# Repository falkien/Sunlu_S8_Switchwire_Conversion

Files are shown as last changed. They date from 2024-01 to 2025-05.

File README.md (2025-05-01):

# Sunlu_S8_Switchwire_Conversion

***UPDATE 05/01/25*** I recently sold my Switchwire. I am going to leave this page up for anyone in the future looking for info on a Sunlu S8 Switchwire conversion

***UPDATE 07/27/24*** Look for major changes in this entire section over the next couple of weeks. I am redoing the entire electronics and Skirt area. This includes all new skirts, upgrade to the SKR Mini E3 V3, and replacing the PVC electronic cover panels with printed pieces. 

You will find here all the files needed to upgrade your Sunlu S8 to a Voron Switchwire. This is a work in progress so please bear with me. <br />
<br />
This will hopefully have everything that you need to do a conversion. It has taken me several months to get this up and running and I will also be updating this as I go, so excuse the gramar and layout as I am new to github.  <br />
 <br />
Rails purchased <br />
<br />
(4) 450mm - (2) MGN12H rails for Y and (2) MGN12H rails for Z <br />
<br />
(1) 348mm - MGN12H rail for X <- Custom cut to fit, could use a 350mm <br />
<br />
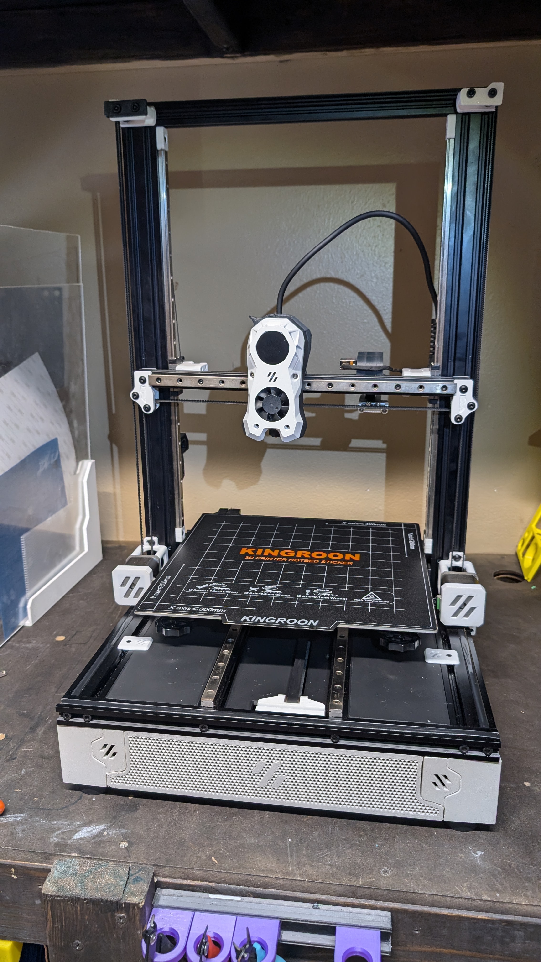
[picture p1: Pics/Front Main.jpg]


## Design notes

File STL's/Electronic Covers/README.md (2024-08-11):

Update the skirt to the mesh skirt. These are taken from the flat mesh skirts from Thejiral on printables. Front and back are from the 250mm trident and the sides are the 350mm trident sides reduced by about 4.5%. I have 2 differnet versions I chose the 354.18mm ones as they left a little wiggle room. If you wish to resize these yourself take the file (Trident-original-Side-skirt-V2-350_2x_RESIZE.3mf) and unlock the scaling lock and resize the X down around 94-95%. The is not the ideal way to do this, but as I have stated elseware I am no good at 3d CAD programs. I will also add a 40mm fan insert for the sides since I am not runing 60mm fans on this setup. The Front skirt could be reduced to about 99%, I just sanded it down just a little to make it fit.

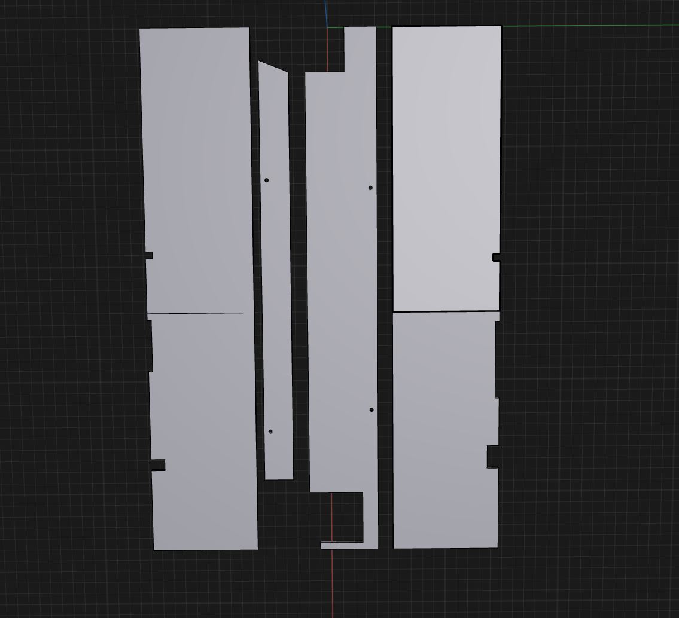
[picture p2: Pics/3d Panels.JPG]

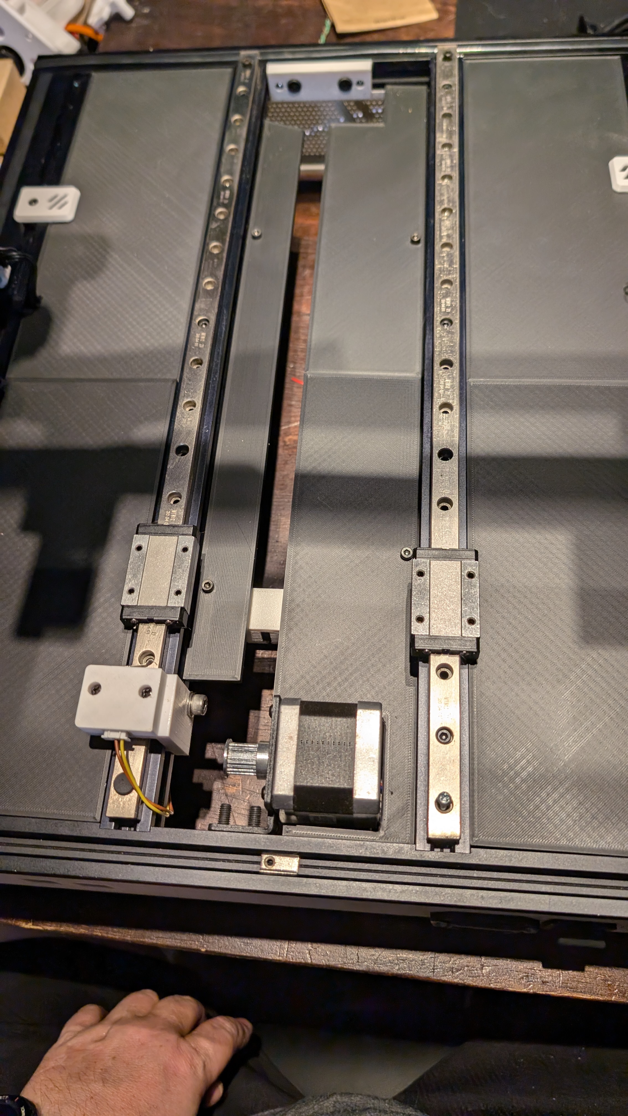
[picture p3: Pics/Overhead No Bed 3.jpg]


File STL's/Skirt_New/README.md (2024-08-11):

Update the skirt to the mesh skirt. These are taken from the flat mesh skirts from Thejiral on printables. Front and back are from the 250mm trident. 
There are 2 different versions the originals and the ones that have 274.1mm (274.8mm original size) in them. These are reduced by 99.75% from the originals. The originals can fit but it VERY tight. 
The sides are the 350mm trident sides reduced by about 4.5%. I have 2 differnet versions I chose the 354.18mm ones as they left a little wiggle room. If you wish to resize 
these yourself take the file (Trident-original-Side-skirt-V2-350_2x_RESIZE.3mf) and unlock the scaling lock and resize the X down around 94-95%. I know this is the is not the 
ideal way to do this, but as I have stated elseware I am no good at 3d CAD programs. I will also add a 40mm fan insert for the sides since I am not runing 60mm fans on this setup. Here is where I got the files.

https://www.printables.com/model/644512-flat-mesh-skirt-voron-trident-350300250mm

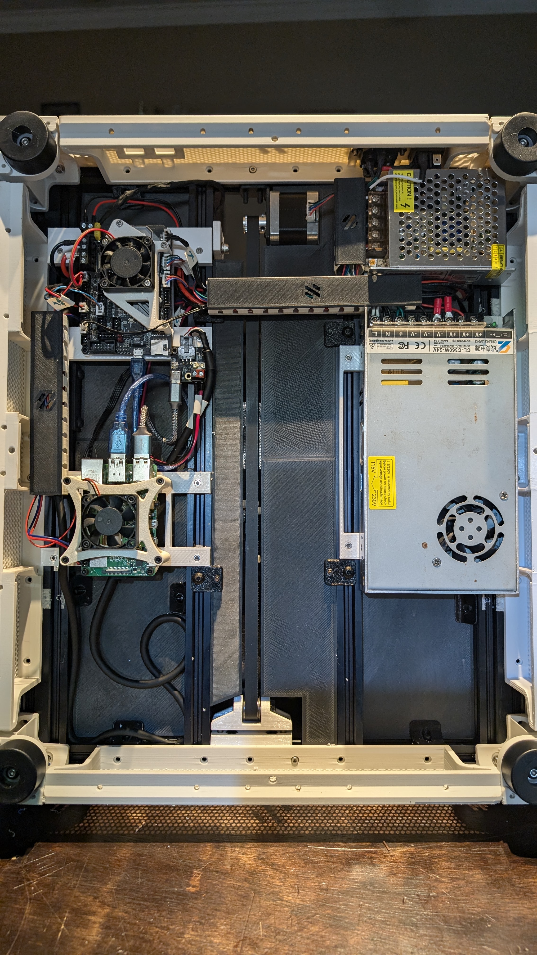
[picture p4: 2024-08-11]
Pics/Electronics Main.jpg

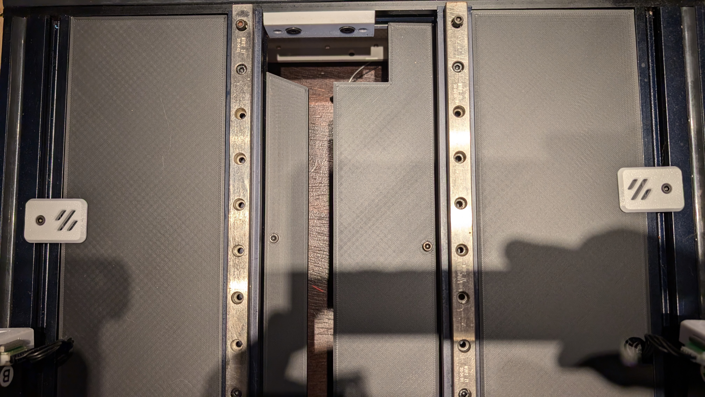
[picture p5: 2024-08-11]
Pics/Overhead No Bed Front 2.jpg

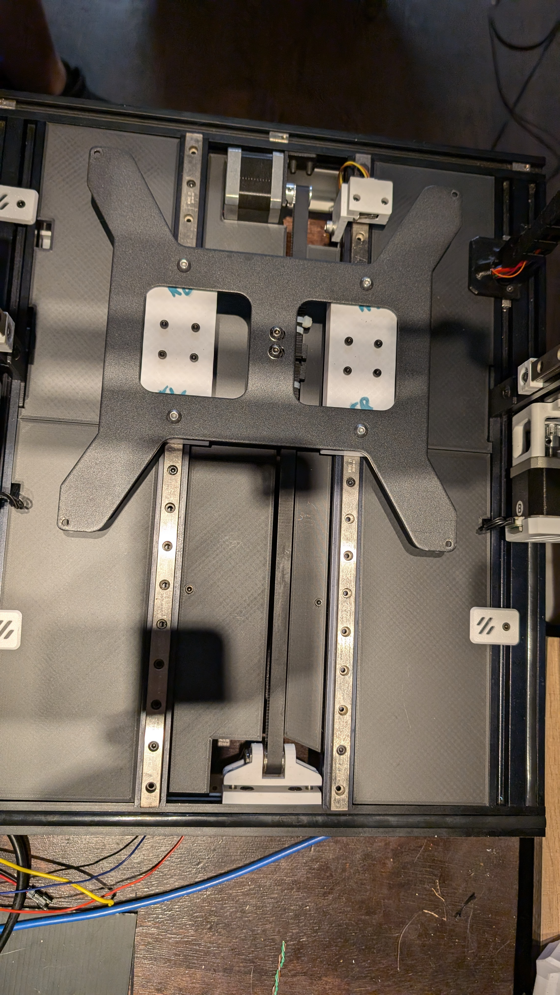
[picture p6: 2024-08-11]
Pics/Overhead No Bed.jpg

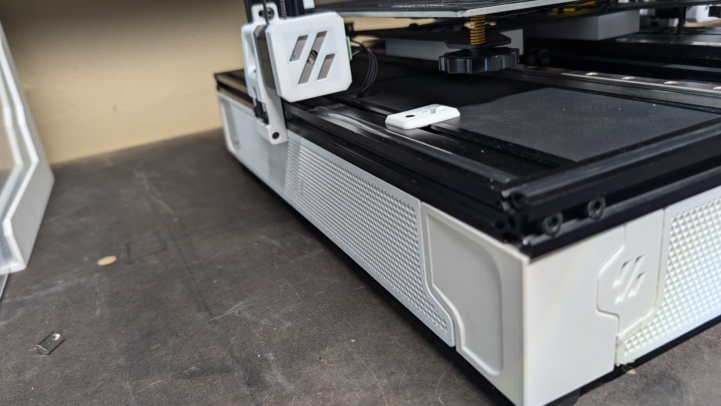
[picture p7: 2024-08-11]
Pics/Left Skirt.jpg

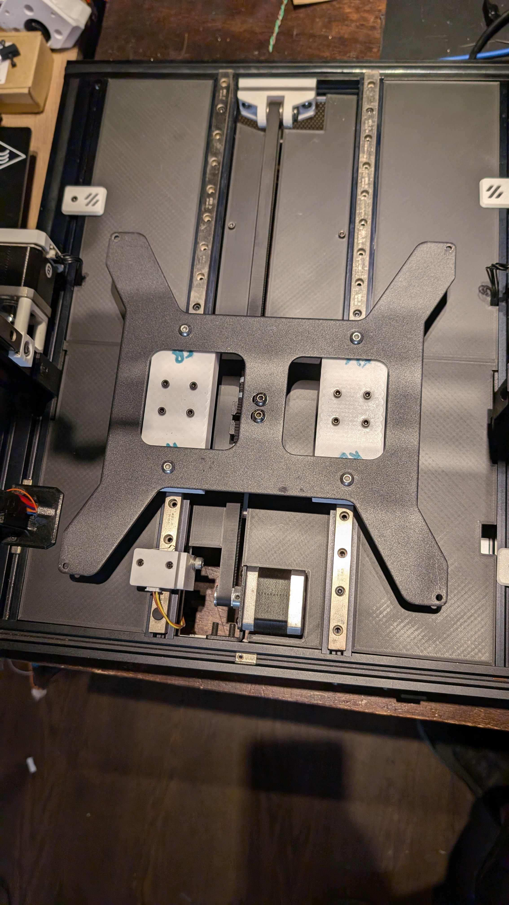
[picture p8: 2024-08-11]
Pics/Overhead No Bed 2.jpg

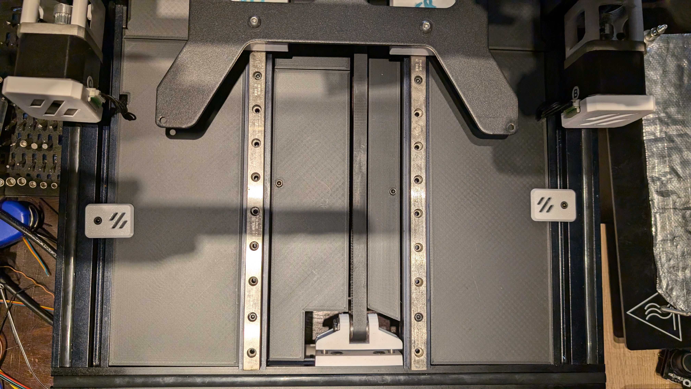
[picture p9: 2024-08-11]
Pics/Overhead no bed Front.jpg

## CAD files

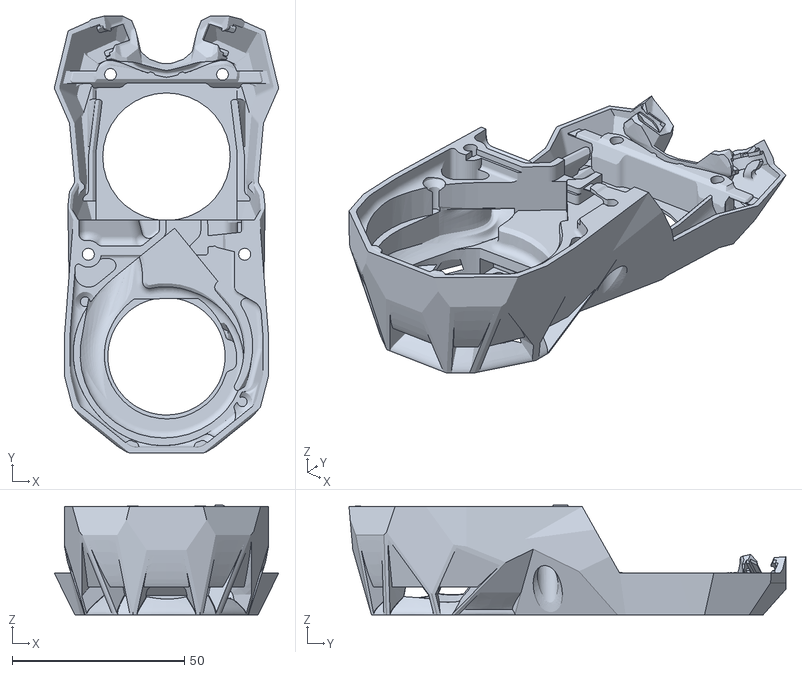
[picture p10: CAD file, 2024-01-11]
STL's/X axis/Knomi Screen/StealthBurner Main Body for KNOMI.STL
65.1 x 126.8 x 31.8

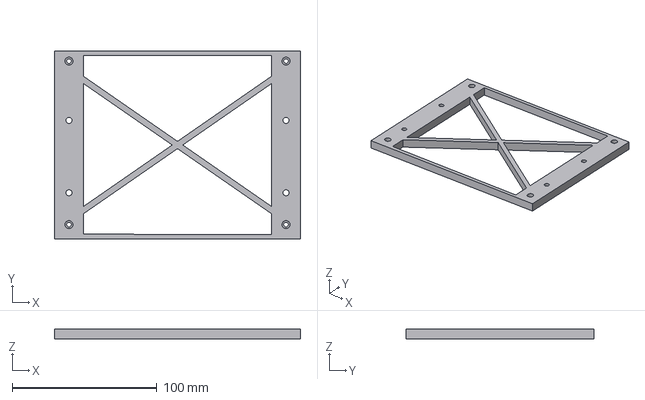
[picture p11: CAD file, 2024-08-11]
STL's/Electronics_Bay/Switchwire_Sunlu_S8_Main_PSU_Mount.step
170.0 x 130.0 x 7.00 mm

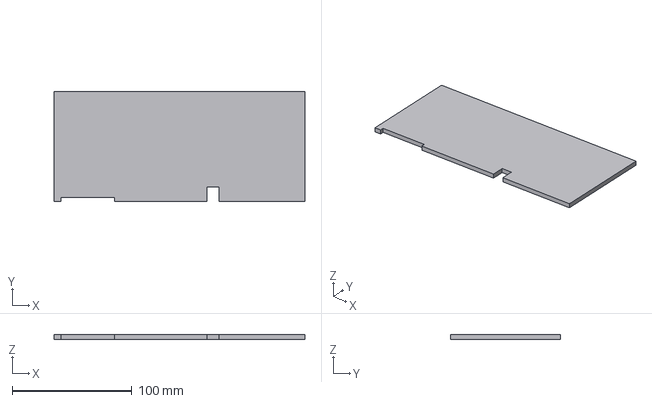
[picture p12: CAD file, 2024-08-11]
STL's/Electronic Covers/Switchwire_Sunlu_S8_Right_Rear.step
210.0 x 92.0 x 4.00 mm

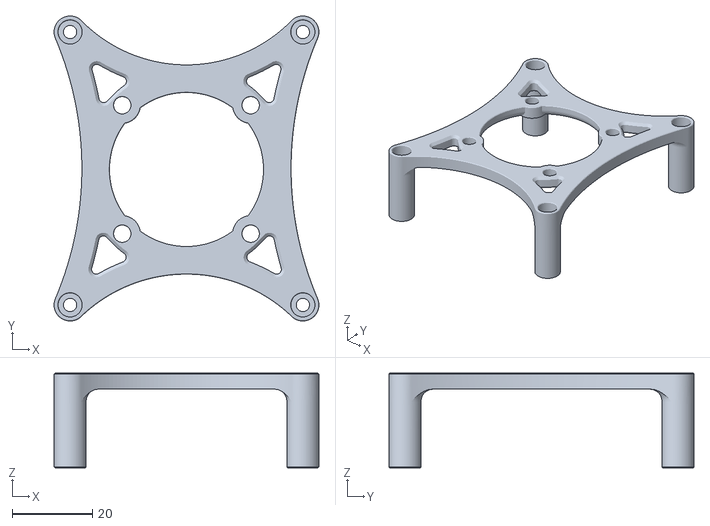
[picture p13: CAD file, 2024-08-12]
STL's/Electronics_Bay/RPI fan mount top.stl
66.0 x 76.0 x 23.6

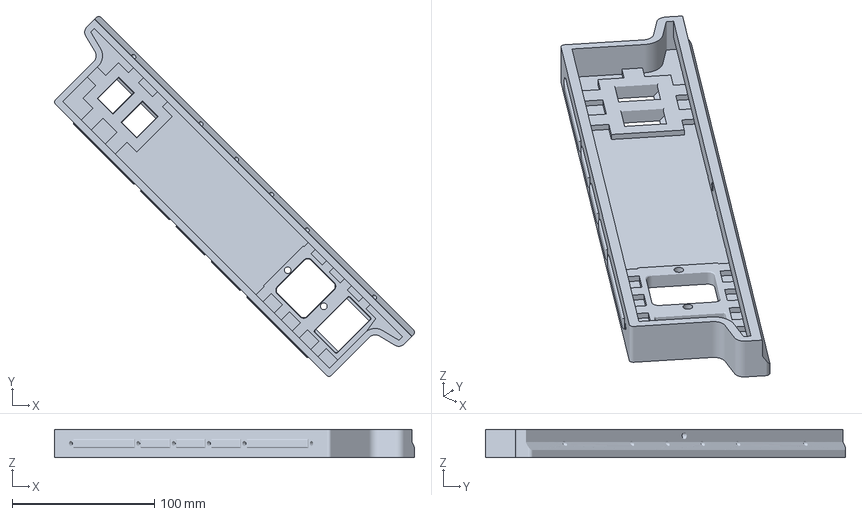
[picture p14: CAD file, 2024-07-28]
STL's/Skirt_New/Sunlu-S8_Switchwire-back-stocksocket_1x_274.1.3mf
253.2 x 253.2 x 20.0 mm

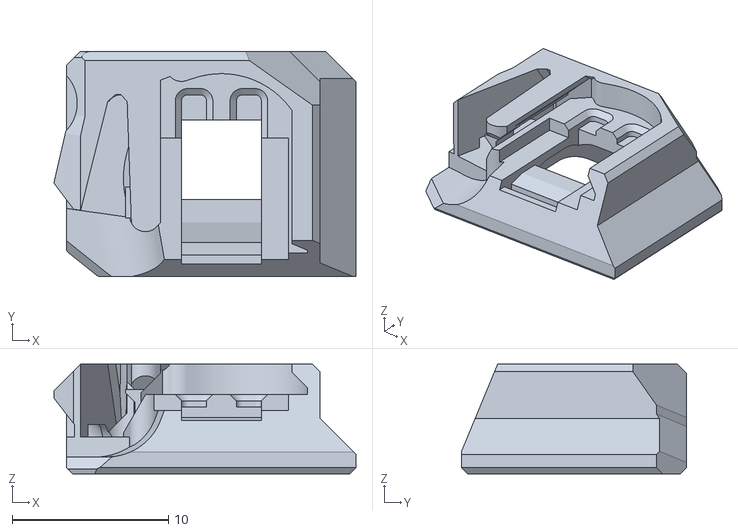
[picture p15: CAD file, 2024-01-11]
STL's/Stealthburner/[o]_stealthburner_LED_carrier.stl
19.3 x 14.4 x 7.01

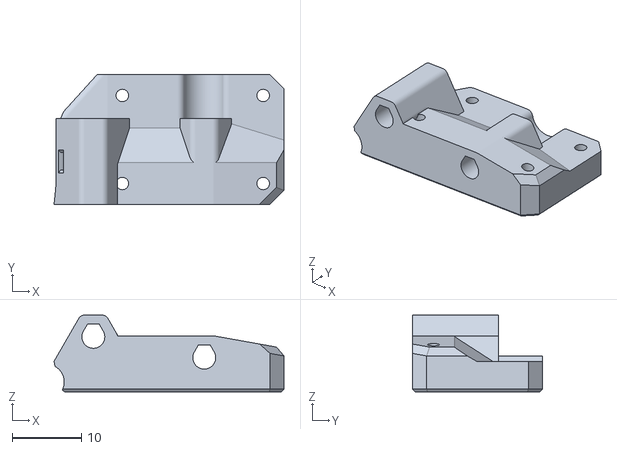
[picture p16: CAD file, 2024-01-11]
STL's/Stealthburner/ADXL345_Mounts/sb_adxl_mount_adafruit_LIS3DH.stl
33.2 x 18.7 x 11.1

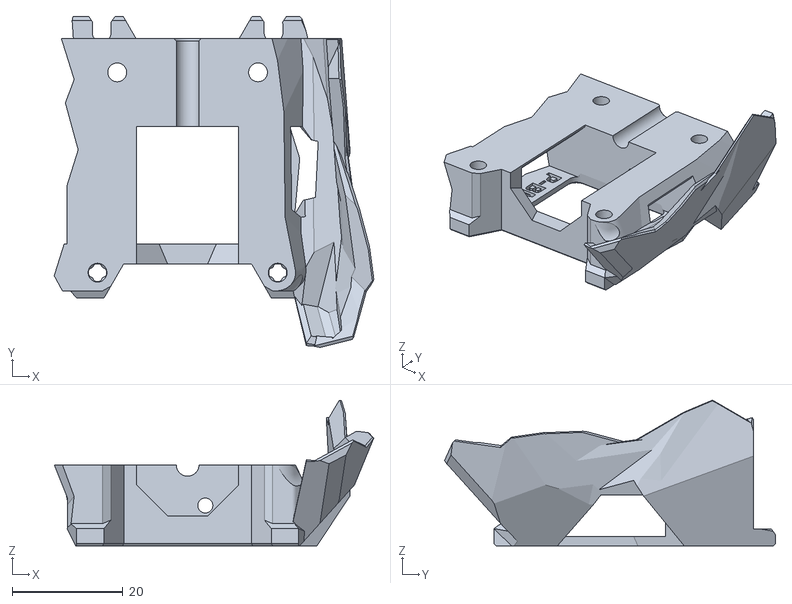
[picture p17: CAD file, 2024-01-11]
STL's/Stealthburner/Printheads/phaetus_bmo/stealthburner_printhead_phaetus_bmo_rear_cw2.stl
57.7 x 59.7 x 26.3

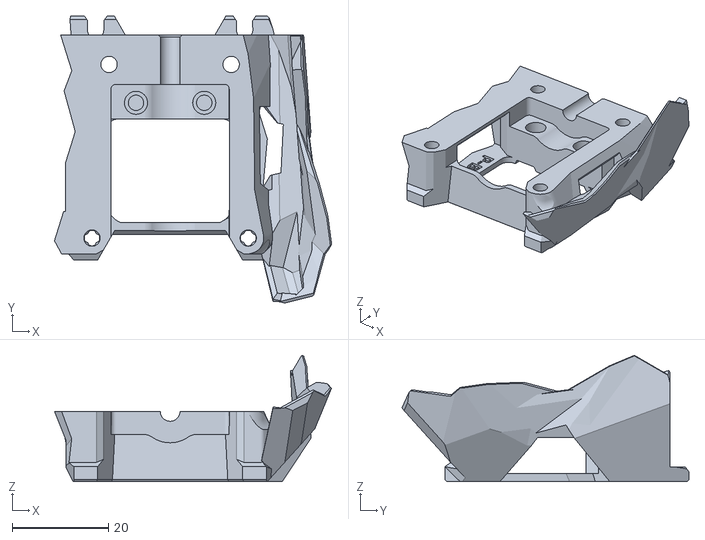
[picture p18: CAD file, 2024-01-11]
STL's/Stealthburner/Printheads/phaetus_bms/stealthburner_printhead_phaetus_bms7_rear_cw2.stl
57.7 x 59.7 x 26.3

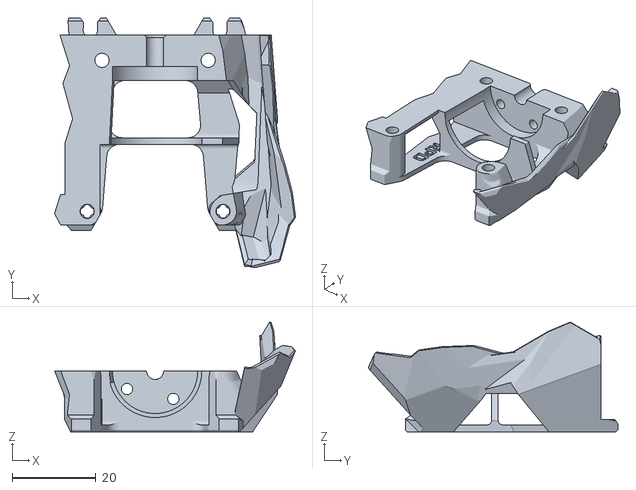
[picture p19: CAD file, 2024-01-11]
STL's/Stealthburner/Printheads/phaetus_rapido/stealthburner_printhead_rapido_rear_cw2.stl
57.7 x 59.7 x 26.3

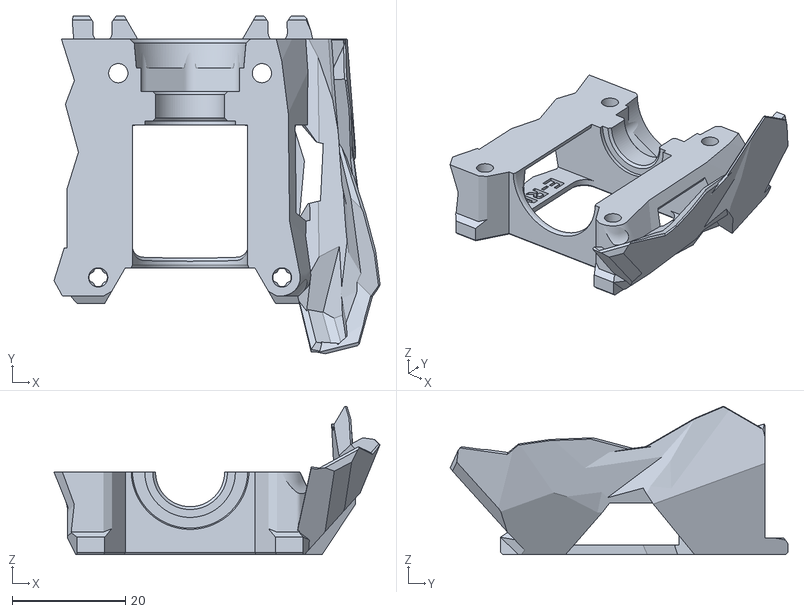
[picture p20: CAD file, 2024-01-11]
STL's/Stealthburner/Printheads/revo_micro/stealthburner_printhead_revo_micro_rear_cw2.stl
57.7 x 59.7 x 26.3

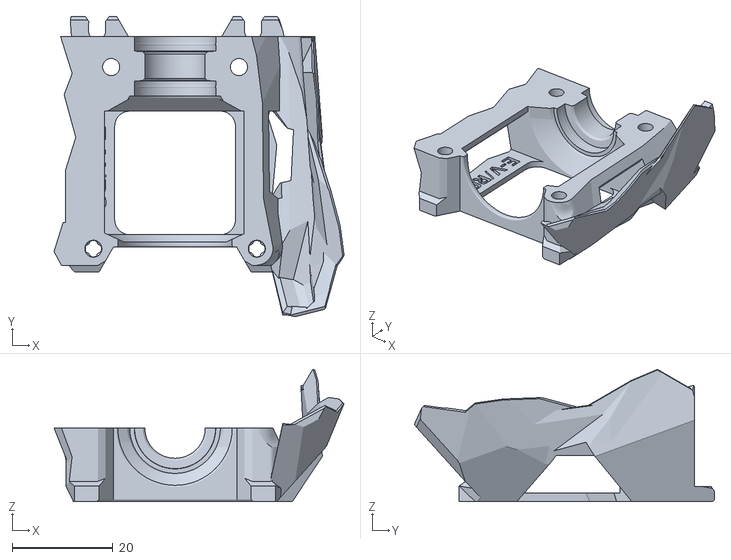
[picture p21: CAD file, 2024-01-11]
STL's/Stealthburner/Printheads/revo_six_and_v6/stealthburner_printhead_v6_r6_rear_cw2.stl
57.7 x 59.7 x 26.3

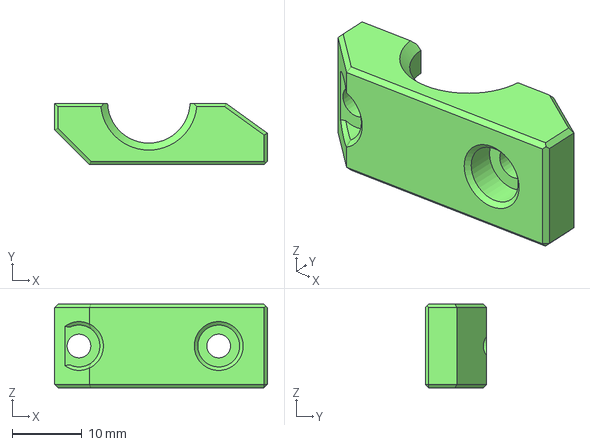
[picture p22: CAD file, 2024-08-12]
STL's/Toolhead_Cable_Management/cw2-pug-mount-clamp.3mf
30.5 x 8.80 x 12.0 mm

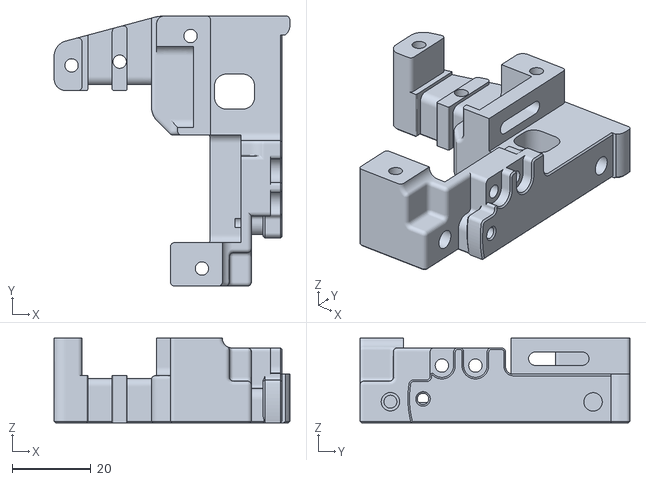
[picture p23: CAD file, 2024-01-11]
STL's/X axis/Frame for inductive probe/Sunlu_X_frame_SW_left.stl
60.0 x 68.8 x 21.6

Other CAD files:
STL's/Stealthburner/Printheads/phaetus_dragon/stealthburner_printhead_dragon_rear_cw2.stl
STL's/Stealthburner/Printheads/revo_voron/stealthburner_printhead_revo_voron_rear_cw2.stl
STL's/X axis/Swichwire_reverse_bowden_.stl
STL's/Y axis/Sunlu_Y_Axis_rail_adaptor.stl
STL's/Electronic Covers/Switchwire Sunlu S8 Panels.step
STL's/Electronic Covers/Switchwire_Sunlu_S8_Left_Center.step
STL's/Electronic Covers/Switchwire_Sunlu_S8_Left_Center.stl
STL's/Electronic Covers/Switchwire_Sunlu_S8_Left_Front.step
STL's/Electronic Covers/Switchwire_Sunlu_S8_Left_Front.stl
STL's/Electronic Covers/Switchwire_Sunlu_S8_Left_Rear.step
STL's/Electronic Covers/Switchwire_Sunlu_S8_Left_Rear.stl
STL's/Electronic Covers/Switchwire_Sunlu_S8_Right_Center.step
STL's/Electronic Covers/Switchwire_Sunlu_S8_Right_Center.stl
STL's/Electronic Covers/Switchwire_Sunlu_S8_Right_Front.step
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

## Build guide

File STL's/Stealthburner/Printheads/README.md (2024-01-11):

# Printheads for Stealthburner.

Choose files containing ***front*** based on your hotend and ***rear_cw1*** / ***rear_cw2*** based on whether you're using the original Clockwork (CW1) or the new Clockwork2 (CW2) extruder.

## Printhead Compatibility:

| Hotend | Compatible Parts | Mounting Hardware | Notes |
| :---: | :---: | :---: | :---:
| Phaetus/Trianglelab Dragon | (P-DRG) | 4x M2.5x8mm | Remove the screws attaching the groove-mount adaptor to access the hard mounting points. |
| Phaetus BMO | (P-BMO) | 4x M2.5x8mm | Unscrew the groove-mount adaptor to access the hard mounting points. |
| Phaetus BMS (6 fins) | (P-BMS6) | 2x M3x12mm | Phaetus has two versions of the BMS; Count the number of fins on your hotend to determine your version. |
| Phaetus BMS (7 fins) | (P-BMS7) | 2x M3x12mm | Phaetus has two versions of the BMS; Count the number of fins on your hotend to determine your version. |
| Phaetus Rapido | (P-RPD) | 4x M2.5x8mm | Only the standard Rapido is supported (No UHF support). See the additional note about [heatsink orientations](phaetus_rapido/README.md). |
| E3D Revo Micro | (E-RM) | M12x1.5mm Plastic Nut | If your mount nut has a ridge on it, put that to the top. |
| E3D Revo Six | (E-V/R6) | N/A |  |
| E3D V6 | (E-V/R6) | N/A |  |
| E3D Revo Voron | (E-RV) | 4x M3x8mm |  |

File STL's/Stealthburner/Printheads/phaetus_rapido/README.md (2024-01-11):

## Phaetus Rapido High Flow mount

### BOM

- One front printed part
- One rear printed part
- Heatset inserts
- Four M2.5x8 socket screws, which should be provided in your Rapido kit
- Two M3x12 socket screws
- PTFE tube

### Instructions

- Add two heatset inserts on the front printed part. Add an additional two if you plan to use the ADXL PCB mount.
- Remove the adapter and bowden collet from the Rapido's heatsink by unscrewing the two M2.5x5 screws:
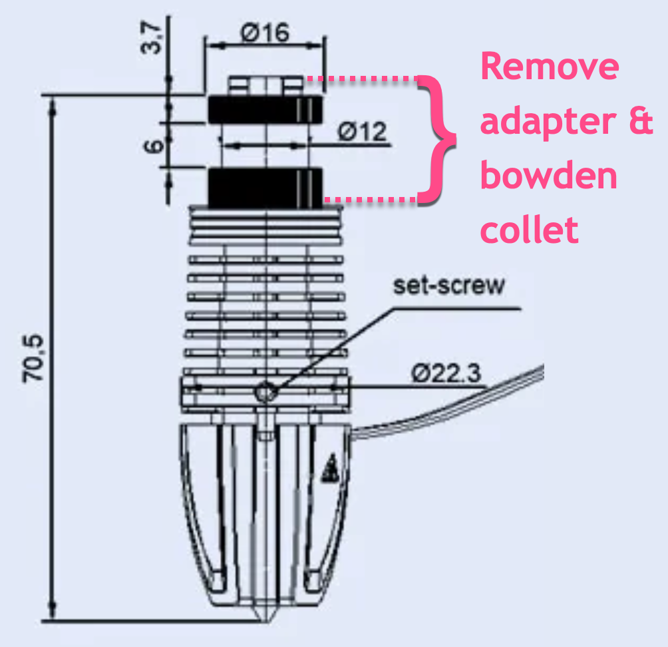
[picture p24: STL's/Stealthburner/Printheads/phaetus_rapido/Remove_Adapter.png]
Remove adapter
  
- Place the hotend in the front printed part and secure it by screwing two M2.5x8 screws into the heatsink.
- Secure the front and rear printed parts together with two M3x12 screws.
- Secure the hotend with the rear part by screwing two M2.5x8 screws into the heatsink.
- Insert the PFTE tube at the top of the mount.

### A note about Rapido orientations

Depending on where the Rapido is sourced, it may come in one of two unsupported heatsink orientations.

To change the orientation of heatsink, first loosen the grub screw on the side and then remove the 3 screws around the heater core. The heatsink can then be rotated +/- 120° into the correct orientation. Be careful not to over-tighten the screws when reassembling as this could cause the heatbreak to bend.

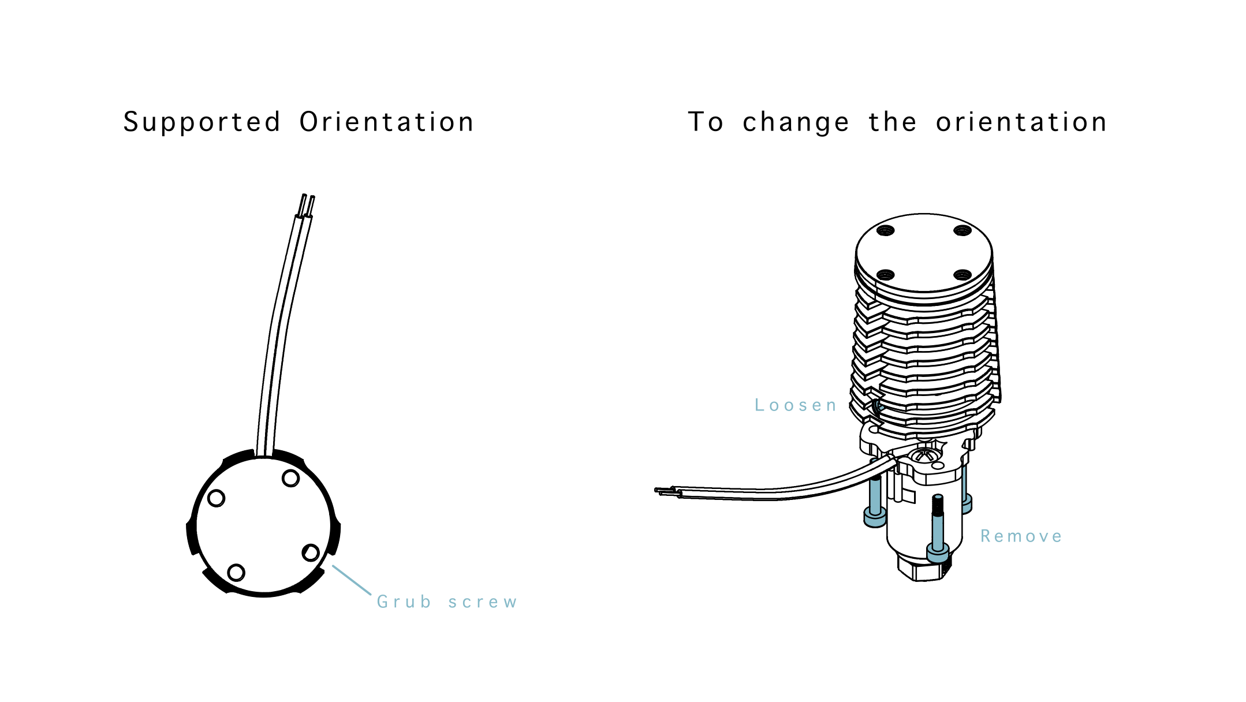
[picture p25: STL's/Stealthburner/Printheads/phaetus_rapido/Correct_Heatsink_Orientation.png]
Correct Heatsink Orientation


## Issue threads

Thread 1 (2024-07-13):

Would we be able to get the .step or .f3d files for this?

yourbuddydinec, 2024-07-13:
Hi there. I saw in the `Sunlu_Skirt_Rear_W-Fans_v2.stl` file that the model seemed messed up? Part is floating if printed flat also the middle fan hole seems to start/end abruptly? I would like to be able to change it up and/or fix it if able but the f3d or step file would really help in that. Also wanted to add a knomi mount to the front skirt so it would also help that. Thanks!

Floating part:
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
Half hole:
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
Abrupt start/end
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

falkien, 2024-07-13:
Yeah when I made those I actually put them together in prusa slicer. They weren't actually made in a 3D CAD program. That's why they're so messed up. I actually don't have step files or CAD files that I could share. I took the STL files and literally put them together in prusa slicer so they would print out. I'm actually going to work on fixing this the proper way sometime soon and we'll gladly share any files that I have or make with you if you're interested.

falkien, 2024-08-11:
I updated my skirt section. This is a way better setup than I had before and gets rid of all the problems from the previous setup. https://github.com/falkien/Sunlu_S8_Switchwire_Conversion/tree/main/STL's/Skirt_New

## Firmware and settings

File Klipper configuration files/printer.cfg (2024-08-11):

# Falkien's Sunlu S8 with SKR 1.4t and 2209 stepper motors
# Switchwire conversion Stealthburner Clockwork mod 
# V6 CHC nozzle Hart PCB board
# 02/10/24 Added Start and End Macros. KAMP still not working

# ------------------------------start--------------------------------------------#
# ================================================================================
# printer
# ================================================================================

[printer]
kinematics: corexz
max_velocity: 300
max_accel: 4500
max_z_velocity: 75
max_z_accel: 1000
square_corner_velocity: 4.0

#[input_shaper]
#shaper_freq_x: 57.6
#shaper_type_x: mzv
#shaper_freq_y: 38
#shaper_type_y: ei


[include mainsail.cfg]
[include KAMP_Settings.cfg]
[exclude_object]
[include stealthburner_leds.cfg]
#[include knomi_status.cfg]
[include klicky-probe.cfg]


# ================================================================================
# mcu
# ================================================================================

[mcu]
serial: /dev/serial/by-path/platform-fd500000.pcie-pci-0000:01:00.0-usb-0:1.1:1.0

# ================================================================================
# Toolhead mcu
# ================================================================================

[mcu nhk]
##  Obtain definition by "ls -l /dev/serial/by-id/" then unplug to verify
##--------------------------------------------------------------------
#serial: /dev/serial/by-id/usb-Klipper_rp2040_E012345678900000-if00
serial: /dev/serial/by-path/platform-fd500000.pcie-pci-0000:01:00.0-usb-0:1.3:1.0
restart_method: command
##--------------------------------------------------------------------




#####################################################################
# X Stepper Settings
# Motor -XM
# Endstop - X-STOP
#####################################################################

[stepper_x]
step_pin: PB13
dir_pin: PB12
enable_pin: !PB14
microsteps: 16
rotation_distance: 40
full_steps_per_rotation:200
endstop_pin: nhk:gpio13
position_endstop: 295
position_min: 0
position_max: 295
homing_speed: 100

# ================================================================================
# tmc2209 stepper_x
# ================================================================================

[tmc2209 stepper_x]
uart_pin: PC11
tx_pin: PC10
uart_address: 0
interpolate: True
run_current: 0.9
stealthchop_threshold: 0

# ================================================================================
# Y Stepper Settings
# Motor -YM
# Endstop - Y-STOP
# ================================================================================

[stepper_y]
step_pin: PB10
dir_pin: !PB2
enable_pin: !PB11
microsteps: 16
rotation_distance: 40
full_steps_per_rotation:200
homing_retract_dist: 0
endstop_pin: PC1
position_endstop: 0
#position_min: 0
position_max: 279
homing_speed: 100
homing_positive_dir: false

# ================================================================================
# tmc2209 stepper_y
# ================================================================================

[tmc2209 stepper_y]
uart_pin: PC11
tx_pin: PC10
uart_address: 2
interpolate: True
run_current: 0.89
stealthchop_threshold: 0


# ================================================================================
# Z Stepper Settings
# Motor -ZAM
# Endstop - Z-STOP
# ================================================================================

[stepper_z]
step_pin: PB0
dir_pin: PC5
enable_pin: !PB1
microsteps: 16
rotation_distance: 40
position_min: -5
homing_speed: 10
position_max: 380
endstop_pin: PC2
#z_offset: 1.0
# homing_retract_dist: 6.0
#position_endstop: 0.0
endstop_pin: probe:z_virtual_endstop

# ================================================================================
# tmc2209 stepper_z
# ================================================================================

[tmc2209 stepper_z]
uart_pin: PC11
tx_pin: PC10
uart_address: 1
interpolate: True
run_current: 0.9
stealthchop_threshold: 0




# ================================================================================
# extruder
# ================================================================================

[extruder]
step_pin: nhk:gpio23
dir_pin: nhk:gpio24
enable_pin: !nhk:gpio25
microsteps: 32
gear_ratio: 50:17
rotation_distance: 13.84 
nozzle_diameter: 0.400
filament_diameter: 1.750
heater_pin: nhk:gpio9
sensor_type: ATC Semitec 104GT-2
sensor_pin: nhk:gpio29
pullup_resistor: 2200
pressure_advance: 0.05
pressure_advance_smooth_time: 0.06
#control: pid
#pid_kp: 25.588
#pid_ki: 1.496
#pid_kd: 109.388
min_temp: 0
max_temp: 290
max_extrude_cross_section: 5
max_extrude_only_distance: 200


[servo klicky_servo]
#check were your servo is wired
pin: PC12
maximum_servo_angle: 150
minimum_pulse_width: 0.00025
maximum_pulse_width: 0.0024

[gcode_macro _servo_test_angle]
gcode:
	{% set ANGLE  = params.ANGLE|int %}
	
    SET_SERVO SERVO=klicky_servo ANGLE={ANGLE}
    G4 P250
    SET_SERVO SERVO=klicky_servo WIDTH=0.0

# ================================================================================
# tmc2209 extruder
# ================================================================================

[tmc2209 extruder]
sense_resistor: 0.100
uart_pin: nhk:gpio0
tx_pin: nhk:gpio1
interpolate: false
#uart_address: 3
run_current: 0.6
stealthchop_threshold: 0

# ================================================================================
# heater_bed
# ================================================================================

[heater_bed]
heater_pin: PC9
sensor_type: EPCOS 100K B57560G104F
sensor_pin: PC4
#control: pid
#pid_kp: 74.786
#pid_ki: 0.766
#pid_kd: 1825.718
min_temp: 0
max_temp: 115

# ================================================================================
# verify_heater heater_bed
# ================================================================================

[verify_heater heater_bed]
# The stock printer heats slowly due to a large bed and no external MOSFET.
# This should be reduced if an external MOSFET is added to increase max_temp
# and heating rate.
check_gain_time: 240

# ================================================================================
# fan
# ================================================================================


[heater_fan my_nozzle_fan]
pin: nhk:gpio5
tachometer_pin: nhk:gpio16
tachometer_ppr: 2
heater_temp: 50.0
fan_speed: 1.0

#Part cooling fan
[fan]
pin: nhk:gpio6
#tachometer_pin: nhk:gpio17
#tachometer_ppr: 2

[heater_fan klipper_mcu_fan]
pin: PB15
heater_temp: 50.0
fan_speed: 1.0



# ================================================================================
# virtual_sdcard
# ================================================================================

[virtual_sdcard]
path: /home/pi/printer_data/gcodes
on_error_gcode: CANCEL_PRINT

# ================================================================================
# display
# ================================================================================

# Konmi V1 Display



# ================================================================================
# safe_z_home
# ================================================================================

#[safe_z_home]
# home_xy_position: 155, 155 #true home
#home_xy_position: 155, 121 #BL Touch
#speed: 200
#z_hop: 10
#z_hop_speed: 50
#move_to_previous: False

# ================================================================================
# Homing and Bed Leveling
# ================================================================================

[bed_mesh]
speed: 200
horizontal_move_z: 5
fade_start: 1.0
fade_end: 10
fade_target: 0
mesh_min: 1,1 #10, 10
mesh_max: 282,270
probe_count: 7,7
algorithm: bicubic
#bicubic_tension: 0.2
#mesh_pps: 3,3
#move_check_distance: 5
#split_delta_z: .025

[bed_screws]
screw1: 27, 274
screw2: 263, 274
screw3: 263, 34
screw4: 27, 34

[screws_tilt_adjust]
screw1: 27, 243
screw1_name: rear left screw
screw2: 263, 243
screw2_name: rear right screw
screw3: 263, 4
screw3_name: front right screw
screw4: 27, 4
screw4_name: front left screw
horizontal_move_z: 10.
speed: 50.
screw_thread: CW-M4

# ================================================================================
# Temp Sensors
# ================================================================================

[temperature_sensor RPI]
sensor_type: temperature_host

[temperature_sensor Klipper]
sensor_type: temperature_mcu

#[temperature_sensor chamber_temp]
#sensor_type: Generic 3950
#sensor_pin: nhk:gpio28
#min_temp: 0
#max_temp: 100
#gcode_id: chamber_th

#[temperature_sensor nh_temp]
## Nitehawk PCB Sensor
#sensor_type: CMFB103F3950FANT
#sensor_pin: nhk:gpio26
#pullup_resistor: 2200
#min_temp: 0
#max_temp: 100
#gcode_id: nh_th

#[thermistor CMFB103F3950FANT]
#temperature1: 0.0
#resistance1: 32116.0
#temperature2: 40.0
#resistance2: 5309.0
#temperature3: 80.0
#resistance3: 1228.0
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

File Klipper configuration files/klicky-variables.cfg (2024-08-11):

# This macro was provided by discord user Garrettwp to whom i give my thanks for sharing it with me.
# I have tweaked it a lot.
# They are based on the great Annex magprobe dockable probe macros "#Originally developed by Mental,
# modified for better use on K-series printers by RyanG and Trails", kudos to them.
# That macro as since evolved into a klipper plugin that currently is pending inclusion in klipper,
# more information here, https://github.com/Annex-Engineering/Quickdraw_Probe/tree/main/Klipper_Macros
# User richardjm revised the macro variables and added some functions, thanks a lot
# by standing on the shoulders of giants, lets see if we can see further
#
# the current home for this version is https://github.com/jlas1/Klicky-Probe
# the 1000 values below is to give an error instead of doing something wrong, hopefully, this won't be used is a printer larger than 1 meter

[gcode_macro _User_Variables]
variable_verbose:             True    # Enable verbose output
variable_debug:              False    # Enable Debug output
variable_travel_speed:         200    # how fast all other travel moves will be performed when running these macros
variable_move_accel:          1000    # how fast should the toolhead accelerate when moving
variable_dock_speed:            50    # how fast should the toolhead move when docking the probe for the final movement
variable_release_speed:         75    # how fast should the toolhead move to release the hold of the magnets after docking
variable_z_drop_speed:          20    # how fast the z will lower when moving to the z location to clear the probe

variable_safe_z:         	    25    # Minimum Z for attach/dock and homing functions
# if true it will move the bed away from the nozzle when Z is not homed
variable_enable_z_hop:        True    # set this to false for beds that fall significantly under gravity (almost to Z max)

variable_max_bed_y:            295    # maximum Bed size avoids doing a probe_accuracy outside the bed
variable_max_bed_x:            279    # maximum Bed size avoids doing a probe_accuracy outside the bed

# if a separate Z endstop switch is in
# use, specify the coordinates of the switch here (Voron).
# Set to 0 to have the probe move to center of bed
variable_z_endstop_x:         0
variable_z_endstop_y:         0

#Check the printer specific documentation on klipper Dock/Undock configuration, these are dummy values
#dock location
variable_docklocation_x:      235    # X Dock position
variable_docklocation_y:      0    # Y Dock position
variable_docklocation_z:      -128    # Z dock position (-128 for a gantry/frame mount)

#The following variables are used if the dock is deployed and retracted via a servo motor
variable_enable_dock_servo:  True    # Set to true if your klicky dock is servo-controlled
variable_servo_name:        'klicky_servo'    # The name of the dock servo defined in printer.cfg under [servo]
variable_servo_deploy:          60    # This EXAMPLE is the value used to deploy the servo fully
variable_servo_retract:         140    # This EXAMPLE is the value used to retract the servo fully (initial_angle in [servo] config)
variable_servo_delay:          250    # This is a delay to wait the servo to reach the requested position, be carefull with high values

#Dock move, final toolhead movement to release the probe on the dock
#it's a relative move
Variable_dockmove_x:          -40
Variable_dockmove_y:             0
Variable_dockmove_z:             0

#Attach move. final toolhead movement to attach the probe on the mount
#it's a relative move
Variable_attachmove_x:           0
Variable_attachmove_y:           0
Variable_attachmove_z:           0

#Umbilical to help untangle the umbilical in difficult situations
variable_umbilical:          False    # should we untangle the umbilical
variable_umbilical_x:           15    # X umbilical position
variable_umbilical_y:           15    # Y umbilical position

# location to park the toolhead
variable_park_toolhead:      False    # Enable toolhead parking
variable_parkposition_x:       140
variable_parkposition_y:       140
variable_parkposition_z:        30

variable_version:                1    # Helps users to update the necessary variables, do not update if the variables above are not updated

#Below this remark, you normally do not need to configure
#Attach move2
Variable_attachmove2_x:          0    # intermediate toolhead movement to attach
Variable_attachmove2_y:          0    # the probe on the dock
Variable_attachmove2_z:          0    # (can be negative)

variable_home_backoff_x:        10    # how many mm to move away from the X endstop after homing X
                                      # this is useful for the voron v0 to enable the toolhead to move out of the way to allow an unstricted Y homing
variable_home_backoff_y:        10    # how many mm to move away from the Y endstop after homing Y

variable_override_homing:       ''    # configures what axis to home first
                                      #  '' = default klicky behavior (tries to avoid the hitting the dock)
                                      # 'X' = forces X to home first
                                      # 'Y' = forces Y to home first
                                      
variable_dock_on_zhome:       True    # docks the probe on Z Homing if not necessary (avoids hitting the bed on some printers                                      

# Do not modify below
gcode:
    {% set Mx = printer['configfile'].config["stepper_x"]["position_max"]|float %}
    {% set My = printer['configfile'].config["stepper_y"]["position_max"]|float %}
    {% set Ox = printer['configfile'].config["probe"]["x_offset"]|float %}
    {% set Oy = printer['configfile'].config["probe"]["y_offset"]|float %}
    {% set Oz = printer['configfile'].config["probe"]["z_offset"]|float %}

    # If x, y coordinates are set for z endstop, assign them
    {% if z_endstop_x != 0 or z_endstop_y != 0 %}
        SET_GCODE_VARIABLE MACRO=_Probe_Variables VARIABLE=z_endstop_x VALUE={ z_endstop_x }
        SET_GCODE_VARIABLE MACRO=_Probe_Variables VARIABLE=z_endstop_y VALUE={ z_endstop_y }

    # if no x, y coordinates for z endstop, assume probe is endstop and move toolhead to center of bed
    {% else %}
        SET_GCODE_VARIABLE MACRO=_Probe_Variables VARIABLE=z_endstop_x VALUE={ (Mx * 0.5) - Ox }
        SET_GCODE_VARIABLE MACRO=_Probe_Variables VARIABLE=z_endstop_y VALUE={ (My * 0.5) - Oy }
    {% endif %}

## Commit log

2024-01-11 Rename Sunlu PSU mount V1a.stl to Sunlu PSU mount V1a_mirror_x2.stl
    [Sunlu PSU mount V1a_mirror_x2.stl]
2024-01-11 Rename Sunlu PSU mount V1b.stl to Sunlu PSU mount V1b_mirror_x2.stl
    [Sunlu PSU mount V1b_mirror_x2.stl]
2024-01-11 Rename STL's/X axis/Frame for ABL probe/read_me.md to STL's/X axis/Frame for README.md
